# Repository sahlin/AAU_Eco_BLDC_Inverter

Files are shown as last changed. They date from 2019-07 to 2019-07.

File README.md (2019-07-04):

# AAU_Eco_BLDC_Inverter
Aalborg University BLDC control system for Shell EcoMarathon

This hardware achieved a second place in the efficiency competition Shell Ecomarathon Europe 2019 on a special designed hydrogen fueled eco racer car. The car was built by students at Aalborg University - Department of Energy Technology. We achieved a result of 214.27 km/m3 H2 (which is about 620 km/l 95 octane equivalent) and the motor system was a Grundfos PMSM motor and is rated at 2000 RPM, 2 Nm, 10.8V og 38A , but we are pushing it to 60A and 2500 RPM!

It's effectiveness with inverter included is best at 2000+ RPM and >1 Nm (90%), which put it at for our entire run (except for acceleration).

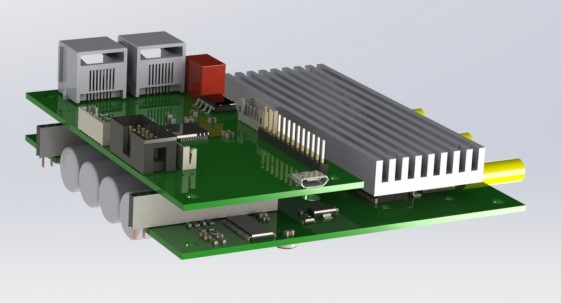
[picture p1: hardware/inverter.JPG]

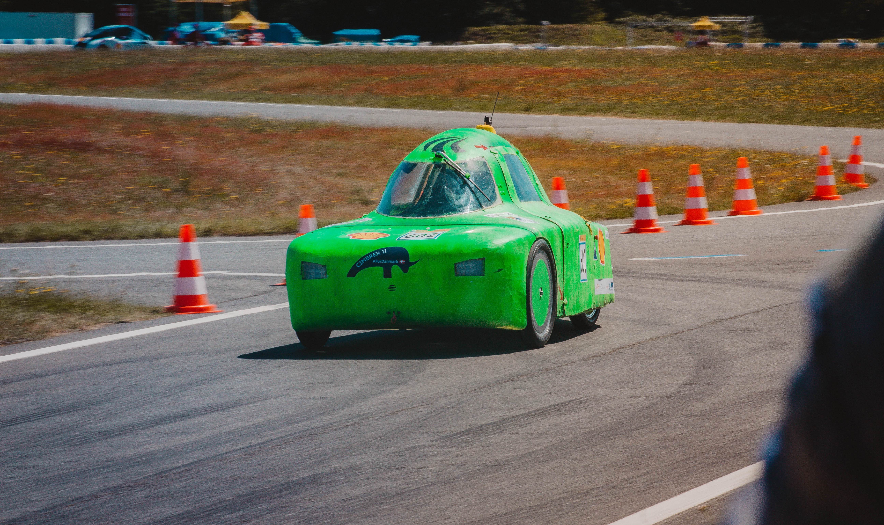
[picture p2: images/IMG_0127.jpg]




The initial work was done by the VESC Project. https://vesc-project.com/

Hardware is licensed under the Creative Commons Attribution-ShareAlike 4.0 International License. To view a copy of this license, visit http://creativecommons.org/licenses/by-sa/4.0/.

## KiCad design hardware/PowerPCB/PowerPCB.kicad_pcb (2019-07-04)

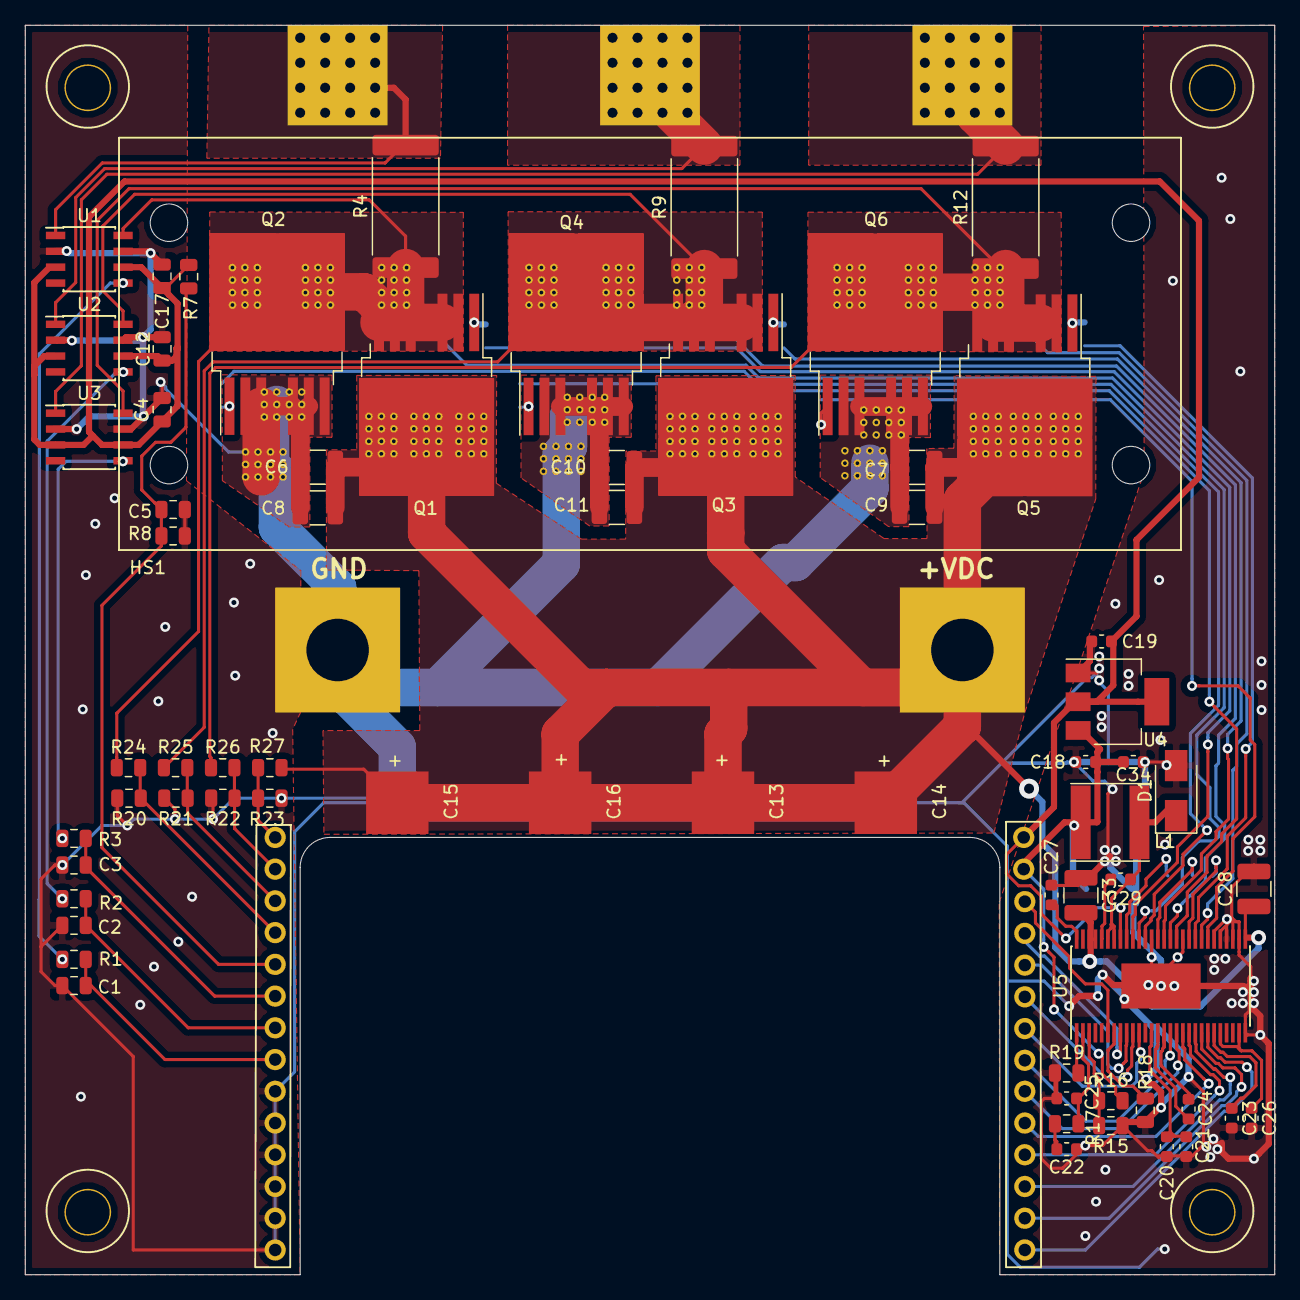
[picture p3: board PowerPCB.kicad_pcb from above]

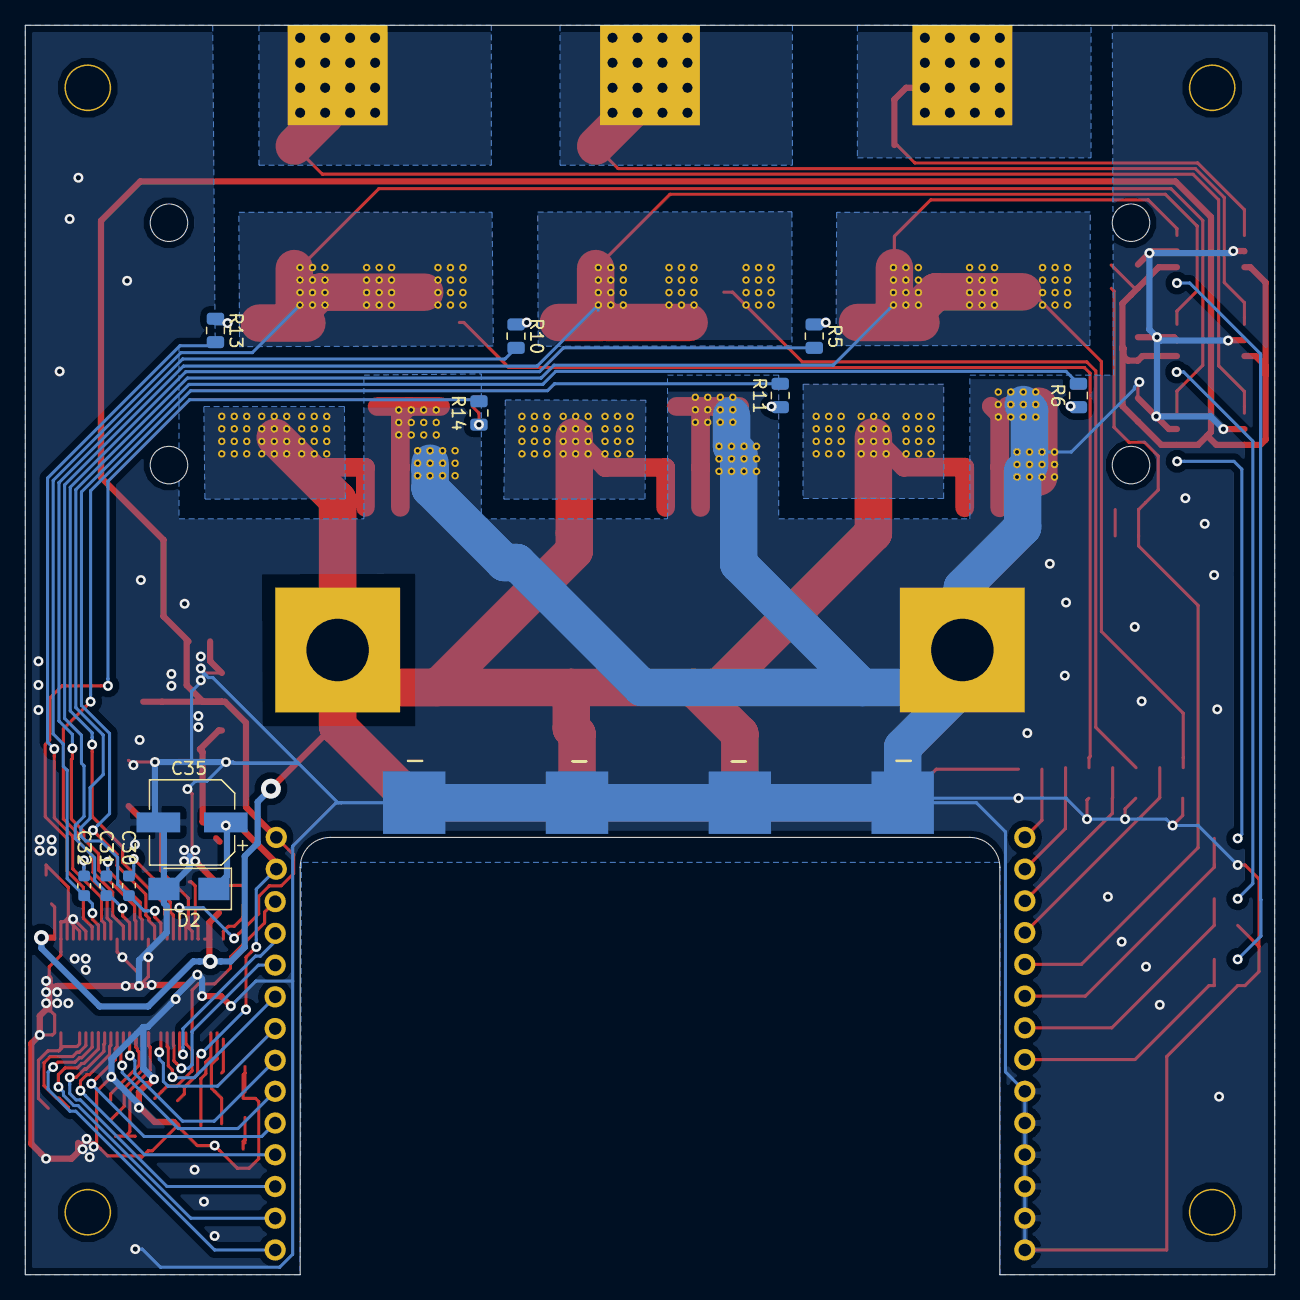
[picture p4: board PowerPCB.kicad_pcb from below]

Board: 2 copper layers, 100.0 x 100.0 mm, 111 parts (11 on the bottom side), 61 nets.

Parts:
C1, C2, C3: 4.7nF; C_0805_2012Metric
C4, C12, C17: 100nF; C_0805_2012Metric
C5: 2.2uF; C_0805_2012Metric
C6, C7, C8, C9, C10, C11, C28, C33: 4.7uF 100V; C_1210_3225Metric
C13, C14, C15, C16: EEUFC1J681L; CAP_inverter
C18, C19, C29: 100nF; C_0603_1608Metric
C20, C21, C23, C26, C34: 2.2uF; C_0603_1608Metric
C22: 6.8nF; C_0603_1608Metric
C24: 22nF; C_0603_1608Metric
C25: 120pF; C_0603_1608Metric
C27: 15nF; C_0603_1608Metric
C30, C31, C32: 220nF; C_0603_1608Metric
C35: 68uF; CP_Elec_6.3x5.7
D1: B360A-13-F; D_SMA
D2: SMAJ5.0A; D_SMA
HS1: Heatsink; HeatSink
J1: InverterConn
J2: PH_A; BulletConnector
J3: VDC; 5mmWireConn
J4: PH_B; BulletConnector
J5: PH_C; BulletConnector
J6: GND; 5mmWireConn
J7, J8, J9, J10: Conn_01x01; Spacer
L1: L; L_Taiyo-Yuden_NR-60xx
Q1, Q2, Q3, Q4, Q5, Q6: IPB010N06N; TO-263-6
R1, R2, R3: 100; R_0805_2012Metric
R4, R9, R12: Shunt 0.0002; R_4020_10251Metric_Pad1.65x5.30mm_HandSolder
R5, R6, R10, R11, R13, R14: 6.8; R_0805_2012Metric
R7: 10k NTC; R_0805_2012Metric
R8, R18: 10k; R_0805_2012Metric
R15: 3.3k; R_0805_2012Metric
R16: 18k; R_0805_2012Metric
R17: 15k; R_0805_2012Metric
R19: 220k; R_0805_2012Metric
R20, R21, R22, R23: 2.2k; R_0805_2012Metric
R24, R25, R26, R27: 39k; R_0805_2012Metric
U1, U2, U3: INA282; SOIC-8_3.9x4.9mm_P1.27mm
U4: TS1117BCW33; SOT-223-3_TabPin2
U5: DRV8301; HTSSOP-56-1EP_6.1x14mm_P0.5mm_EP3.61x6.35mm
Via1, Via2, Via3, Via4, Via5, Via6, Via7, Via8, Via9, Via10, Via11, Via12, Via13, Via14, Via15, Via16, Via17, Via18, Via19, Via20, Via21, Via22, Via23, Via24: Via_array

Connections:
+5V: C18.1, C34.1, C35.1, D2.1, J1.27, L1.1, R16.2, U4.3
+VDC: C6.2, C7.1, C8.1, C9.1, C10.1, C11.1, C13.1, C14.1, C15.1, C16.1, C28.1, C33.2, J3.1, Q1.D, Q3.D, Q5.D, R27.1, U5.29, U5.53, U5.54, Via13.1, Via14.1, Via15.1, Via16.1, Via17.1, Via18.1, Via19.1, Via20.1, Via21.1
/CS: J1.25, U5.8
/CURR_A: C1.1, J1.8, R1.2
/CURR_B: C2.1, J1.7, R2.2
/CURR_C: C3.1, J1.6, R3.2
/DRV8301/AVDD: C26.1, U5.24, U5.27
/DRV8301/BST_BK: C29.2, U5.52
/DRV8301/COMP: C25.2, R17.2, U5.2
/DRV8301/CP1: C24.1, U5.14
/DRV8301/CP2: C24.2, U5.15
/DRV8301/DTC: R18.1, U5.7
/DRV8301/DVDD: C23.1, U5.23
/DRV8301/GH_A: R5.2, U5.47
/DRV8301/GH_B: R10.2, U5.42
/DRV8301/GH_C: R13.2, U5.37
/DRV8301/GL_A: R6.2, U5.45
/DRV8301/GL_B: R11.2, U5.40
/DRV8301/GL_C: R14.2, U5.35
/DRV8301/GVDD: C20.2, C21.2, U5.13
/DRV8301/PH: C29.1, D1.1, L1.2, U5.50, U5.51
/DRV8301/RT_CLK: R19.2, U5.1
/DRV8301/SH_A: C30.1, Q1.S, Q2.D, R4.1, R24.1, U1.8, U5.46, Via1.1, Via2.1, Via3.1
/DRV8301/SH_B: C31.1, Q3.S, Q4.D, R9.1, R25.1, U2.8, U5.41, Via5.1, Via6.1, Via7.1
/DRV8301/SH_C: C32.1, Q5.S, Q6.D, R12.1, R26.1, U3.8, U5.36, Via9.1, Via10.1, Via11.1
/DRV8301/VSENSE: R15.2, R16.1, U5.3
/EN_GATE: J1.21, U5.16
/FAULT: J1.26, U5.6
/INH_A: J1.20, U5.17
/INH_B: J1.18, U5.19
/INH_C: J1.16, U5.21
/INL_A: J1.19, U5.18
/INL_B: J1.17, U5.20
/INL_C: J1.15, U5.22
/Inverter/C_A: R1.1, U1.5
/Inverter/C_B: R2.1, U2.5
/Inverter/C_C: R3.1, U3.5
/SCLK: J1.22, U5.11
/SDI: J1.24, U5.9
/SDO: J1.23, U5.10
/SENS_A: J1.4, R20.1, R24.2
/SENS_B: J1.3, R21.1, R25.2
/SENS_C: J1.2, R22.1, R26.2
/SENS_SUPPLY: J1.1, R23.1, R27.2
/TEMP: C5.1, J1.5, R7.2, R8.1
GND: C1.2, C2.2, C3.2, C4.2, C5.2, C6.1, C7.2, C8.2, C9.2, C10.2, C11.2, C12.2, C13.2, C14.2, C15.2, C16.2, C17.2, C18.2, C19.2, C20.1, C21.1, C22.1, C23.2, C25.1, C26.2, C27.1, C28.2, C33.1, C34.2, C35.2, D1.2, D2.2, J1.9, J1.10, J1.11, J1.12, J1.13, J1.14, J6.1, Q2.S, Q4.S, Q6.S, R8.2, R15.1, R18.2, R19.1, R20.2, R21.2, R22.2, R23.2, U1.2, U1.7, U2.2, U2.7, U3.2, U3.7, U4.1, U5.28, U5.30, U5.31, U5.32, U5.33, U5.34, U5.39, U5.44, U5.57, Via4.1, Via8.1, Via12.1, Via22.1, Via23.1, Via24.1
unnamed: C22.2, R17.1
unnamed: C27.2, U5.56
unnamed: C30.2, U5.48
unnamed: C31.2, U5.43
unnamed: C32.2, U5.38
unnamed: J2.1, R4.2, U1.1
unnamed: J4.1, R9.2, U2.1
unnamed: J5.1, R12.2, U3.1
unnamed: Q1.G, R5.1
unnamed: Q2.G, R6.1
unnamed: Q3.G, R10.1
unnamed: Q4.G, R11.1
unnamed: Q5.G, R13.1
unnamed: Q6.G, R14.1
VCC: C4.1, C12.1, C17.1, C19.1, J1.28, R7.1, U1.3, U1.6, U2.3, U2.6, U3.3, U3.6, U4.2, U5.49

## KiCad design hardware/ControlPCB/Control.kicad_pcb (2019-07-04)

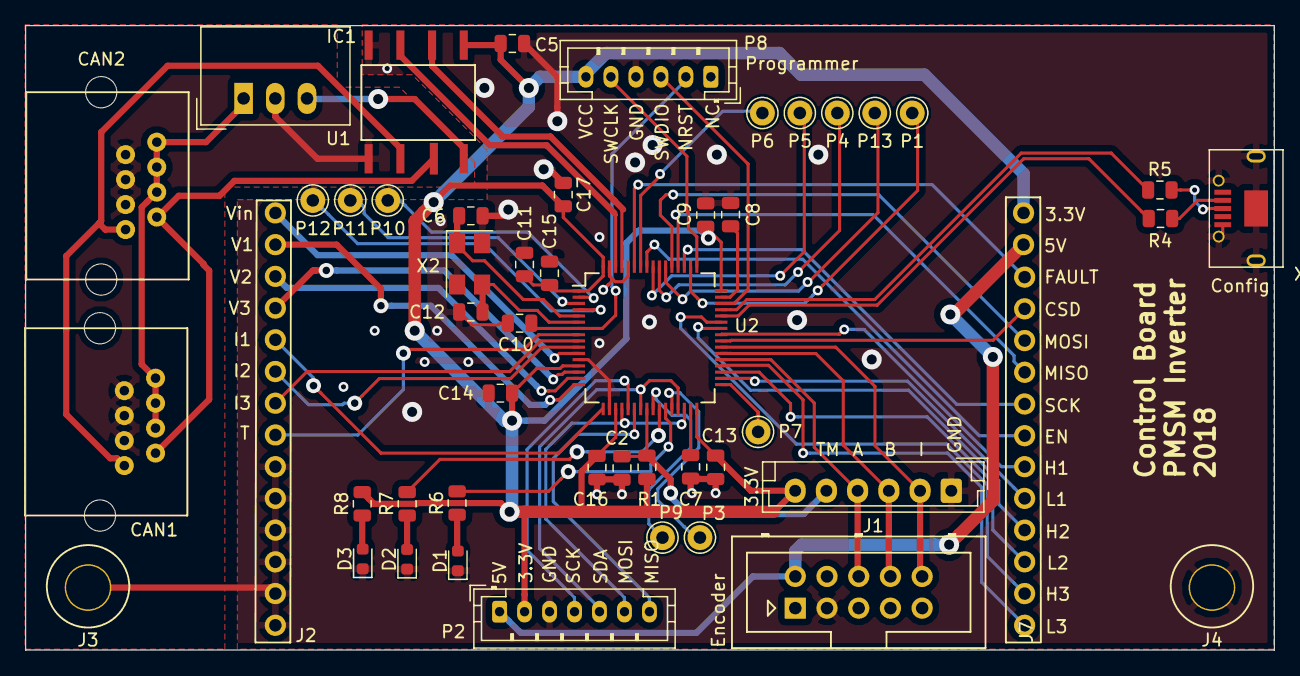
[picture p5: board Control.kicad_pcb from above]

Board: 2 copper layers, 100.0 x 50.0 mm, 48 parts (0 on the bottom side), 65 nets.

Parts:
C2, C10: 100n; C_0805_2012Metric
C5, C7, C8, C9, C11, C13, C14, C15, C16, C17: 2.2u; C_0805_2012Metric
C6, C12: 15p; C_0805_2012Metric
CAN1, CAN2: RJ45CAN; RJ45
D1: RED; LED_0603_1608Metric
D2: GREEN; LED_0603_1608Metric
D3: LED; LED_0603_1608Metric
IC1: ISO1050
J1: Conn_01x06; JST_EH_B06B-EH-A_1x06_P2.50mm_Vertical
J2: InverterConn
J3, J4: Mounting; Spacer
J7: Quadrature Encoder; Multicomp_MC9A12-1034_2x05_P2.54mm_Vertical
P1, P3, P4, P5, P6, P7, P9, P10, P11, P12, P13: CONN_1; Pin_D1.0mm_L10.0mm
P2: PWR_COMM; JST_PH_B7B-PH-K_1x07_P2.00mm_Vertical
P8: SWD; JST_PH_B6B-PH-K_1x06_P2.00mm_Vertical
R1: 10k; R_0805_2012Metric
R4, R5: 22R; R_0805_2012Metric
R6, R7: 100R; R_0805_2012Metric
R8: 2k2; R_0805_2012Metric
U1: TSR_1-2450; Converter_DCDC_TRACO_TSR-1_THT
U2: STM32F405RGTx; LQFP-64_10x10mm_P0.5mm
X1: MINI-USB-SHIELD-32005-201; USB_Micro-AB-MOLEX-47590-0001
X2: 8MHz 10ppm; Crystal_SMD_5032-4Pin_5.0x3.2mm

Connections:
+5V: J2.27, J7.2, P2.1
+12V: CAN1.3, CAN1.5, CAN1.7, CAN2.3, CAN2.5, CAN2.7, U1.1
/A+: J1.4, J7.6, U2.37
/ADC_TEMP: J2.5, U2.17
/B+: J1.3, J7.8, U2.38
/CAN bus transceiver/5V_CAN: IC1.8, U1.3
/CAN bus transceiver/CANH: CAN1.1, CAN2.1, IC1.7
/CAN bus transceiver/CANL: CAN1.2, CAN2.2, IC1.6
/CAN bus transceiver/CAN_RX: IC1.2, U2.61
/CAN bus transceiver/CAN_TX: IC1.3, U2.62
/Current1: J2.8, U2.8
/Current2: J2.7, U2.9
/Current3: J2.6, U2.10
/D+: R5.2, X1.3
/D-: R4.2, X1.2
/EN_GATE: J2.21, U2.57
/FAULT: J2.26, U2.59
/GreenLED: D2.2, R7.1
/H1: J2.20, U2.41
/H2: J2.18, U2.42
/H3: J2.16, U2.43
/I+: J1.2, J7.10, U2.39
/L1: J2.19, U2.34
/L2: J2.17, U2.35
/L3: J2.15, U2.36
/MCU/LED_GREEN: R7.2, U2.26
/MCU/LED_RED: R6.2, U2.27
/MCU/TEMP_MOTOR: C2.2, J1.5, R1.1, U2.24
/MCU/USB_DM: R4.1, U2.44
/MCU/USB_DP: R5.1, U2.45
/MISO_RX_SCL: P2.7, U2.22
/PA15: P1.1, U2.50
/PB2: P3.1, U2.28
/PB3: P4.1, U2.55
/PB4: P5.1, U2.56
/PB6: P6.1, U2.58
/PB12: P7.1, U2.33
/PC5: P9.1, U2.25
/PC13: P10.1, U2.2
/PC14: P11.1, U2.3
/PC15: P12.1, U2.4
/PD2: P13.1, U2.54
/RX_SCL_MOSI: P2.6, U2.20, U2.30
/RedLED: D1.2, R6.1
/SCK_ADC_EXT: P2.4, U2.21
/SPI3_CSD: J2.25, U2.40
/SPI3_MISO: J2.23, U2.52
/SPI3_MOSI: J2.24, U2.53
/SPI3_SCK: J2.22, U2.51
/Supply_SENS: J2.1, U2.11
/TX_SDA: P2.5, U2.23, U2.29
/Voltage1: J2.4, U2.14
/Voltage2: J2.3, U2.15
/Voltage3: J2.2, U2.16
GND: C2.1, C5.2, C6.2, C7.2, C8.2, C9.1, C10.1, C11.1, C12.2, C13.1, C14.1, C15.1, C16.1, C17.1, D1.1, D2.1, D3.1, IC1.4, J1.1, J2.9, J2.10, J2.11, J2.12, J2.13, J2.14, J3.1, J4.1, J7.3, P2.3, P8.4, U2.12, U2.18, U2.60, U2.63, X1.5, X1.6, X2.2, X2.4
GNDCAN: CAN1.4, CAN1.6, CAN1.8, CAN2.4, CAN2.6, CAN2.8, IC1.5, U1.2
NRST: C10.2, P8.2, U2.7
unnamed: C6.1, U2.5, X2.1
unnamed: C7.1, U2.31
unnamed: C8.1, U2.47
unnamed: C12.1, U2.6, X2.3
unnamed: D3.2, R8.1
SWCLK: P8.5, U2.49
SWDIO: P8.3, U2.46
VCC: C5.1, C9.2, C11.2, C13.2, C14.2, C15.2, C16.2, C17.2, IC1.1, J1.6, J2.28, P2.2, P8.6, R1.2, R8.2, U2.1, U2.13, U2.19, U2.32, U2.48, U2.64
